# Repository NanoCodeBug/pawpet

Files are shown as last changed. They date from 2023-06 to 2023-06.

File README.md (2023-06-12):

# PawPet

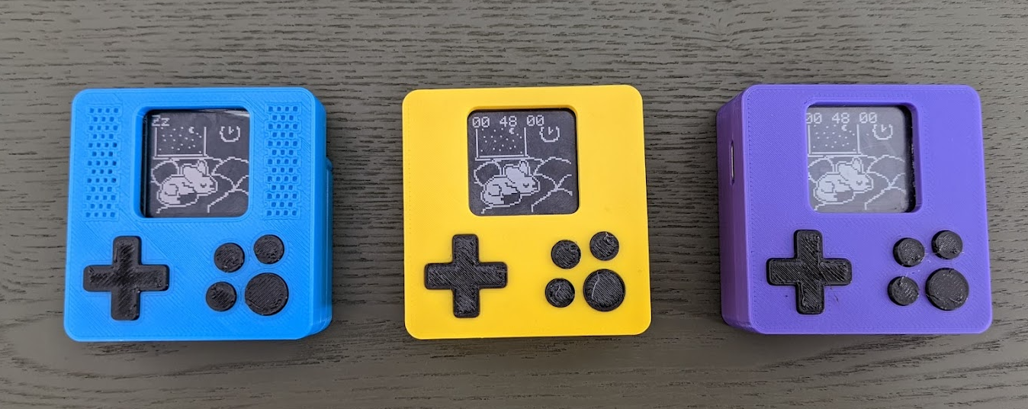
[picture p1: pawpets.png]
PawPet


A virtual pet using the atsamd21g and sharp memory lcd, runs off of 2xAAA for a couple of months. 
See [PawPet on Hacakday.io](https://hackaday.io/project/183032-paw-pet) for full gallery.

This is a rewrite in Rust of the original (and unfinished) arduino based code. That codebase is preserved at [PawPet Arduino](https://github.com/NanoCodeBug/pawpet-arduino).

# Simulator
A webasm simulator of the pawpet using wasm-pack.

This is not a cycle accurate emulator, it hooks the update/render functions to an html5 canvas and maps the core peripherals to web-asm compatible hooks.

1. Install the [Rust](https://www.rust-lang.org/tools/install) SDK

2. Install [wasm-pack](https://rustwasm.github.io/wasm-pack/) (also avaiable via `cargo install wasm-pack`)

3. Run the build script
```
cd pawsim
scripts/build.ps1
```

`index.html` can then be live hosted from the `pawsim\bin` folder, see [pawpet web simulator](https://www.nanocodebug.com/pawpet/index.html) for a working web simulator. 

# Firmware Build Instructions

## Windows
1. Install the [Rust](https://www.rust-lang.org/tools/install) SDK

2. Run sdk-setup, which will setup the rust target dependencies
```
cd pawpet
tools/sdk-setup.ps1
```

3. Run build script
```
cd pawpet
tools/build.ps1
```

## Linux
1. Install [powershell](https://learn.microsoft.com/en-us/powershell/scripting/install/installing-powershell-on-linux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) (i'm sorry, I'll fix this soon)

2. Install the [Rust](https://www.rust-lang.org/tools/install) SDK
3. Install linux dependencies (Ubuntu 20.04) 
```
apt install build-essential libusb-dev libusb-1.0-0-dev libudev-dev pkg-config 
```
4. Run sdk-setup, which will setup the rust target dependencies
```
pwsh
cd pawpet
tools/sdk-setup.ps1
```

5. Run build script
```
pwsh
cd pawpet
tools/build.ps1
```

## Bootloader Flashing
- TODO new hf2 bootloader that supports updating internal flash and extracting save files
- TODO have bootloader support fuse setting

1. disable boot prot fuses
2. flash bootloader generated by `pawboot` module
3. set boot brotection fuses to 16kb (bootprot fuse value 0x2)
4. disable BOD33 fuse 

## Updating Pawpet
- `pawcon` tool supports restarting the pawpet into update mode and flashing new content to its internal storage

# Licensing 

## Code
All code is licensed under the MIT license.

## Assets
All graphics, art, and 3d models are licensed under the Creative Commons Attribution-NonCommercial 4.0 International Public License.

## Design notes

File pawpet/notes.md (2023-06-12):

# TODO
- music playback, music file format
- battery consumption tests

## perf notes
- base screen ~ 5 ms to render empty (battery + peakms counter) frame. 

## Long Term Todo

Bootloader Custom:
- move hf2 file write logic to bootloader, as well as display rendering logic for status
- require hf2 rust impl that can do flash page writes
- would need larger bootloader segment based on file size tests so far, not clear where extra size is comming from compared to c++ bootloader 

## rust firmware validation
- power save tests again
- measure vcom toggle to verify cycling in suspend and wake

# Board Revision Ideas:

revision with p channel mosfets
- that disconnect display power

revision with ldo and p-channel to disconnect battery
- usb power support, see badger2040 switchover design

revision with simple ni-mh charger
- would need big warnings to only use ni-mh batteries

revision with sepearte daughter board for input, more flexibility in case design

revision with silicon contact-pad style buttons, re use existing buttons or cast own

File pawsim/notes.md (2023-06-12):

# todo:
- fm audio synth for beeper
https://rustwasm.github.io/docs/wasm-bindgen/examples/web-audio.html

- frame rate not updating between state changes, need to requery on interval?
- frame rate not syncing, simulator too fast, setInterval drift or issue with main loop?

- onscreen buttons

- look into createImageBitmap?

- remove dependency on wasm-pack
https://rustwasm.github.io/docs/wasm-bindgen/examples/without-a-bundler.html

interesting examples:
https://rustwasm.github.io/docs/wasm-bindgen/examples/2d-canvas.html

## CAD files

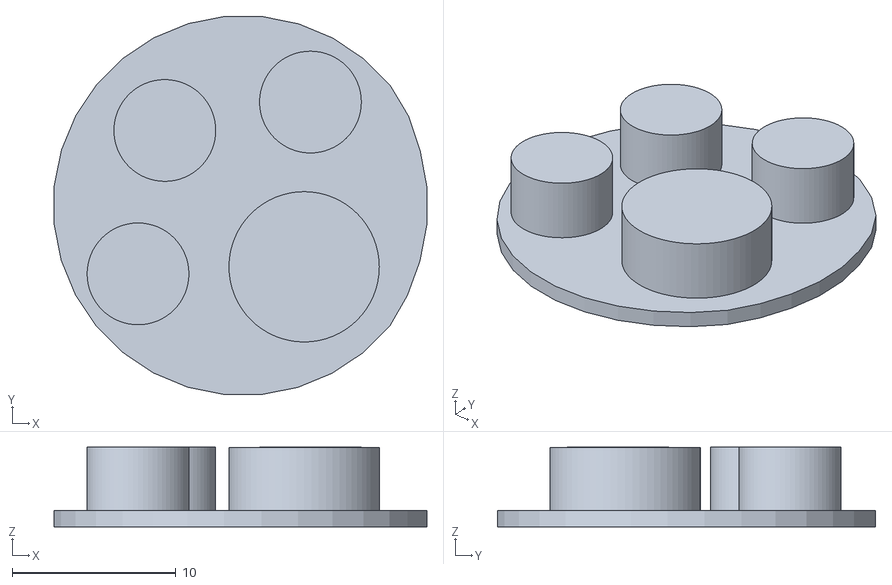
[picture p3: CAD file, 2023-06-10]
case/pawsome-v8-prod-r1-pawPad.stl
22.8 x 23.1 x 4.86

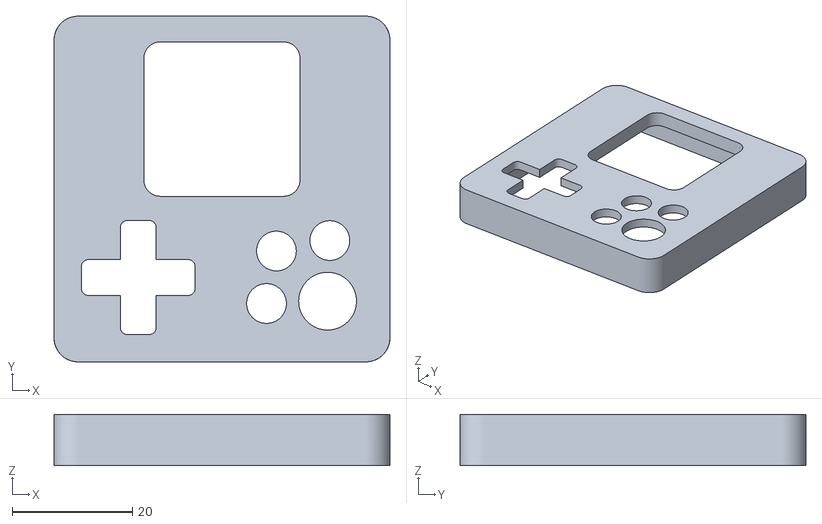
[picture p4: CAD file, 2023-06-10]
case/pawsome-v7-debug-r3-front.stl
55.9 x 57.5 x 8.56

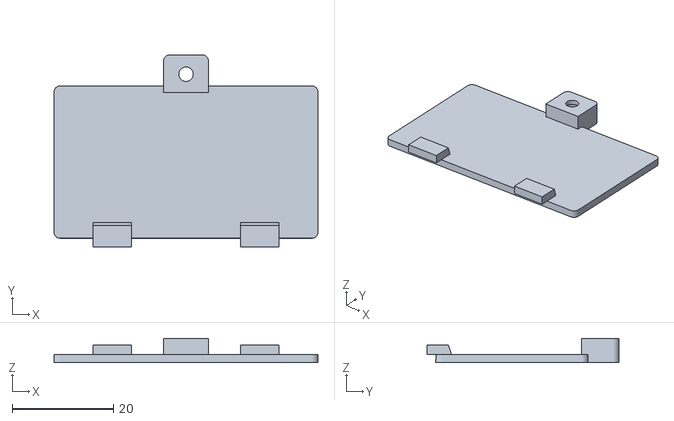
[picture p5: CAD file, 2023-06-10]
case/pawsome-v8-prod-r1-battery-door.stl
52.0 x 37.9 x 4.79

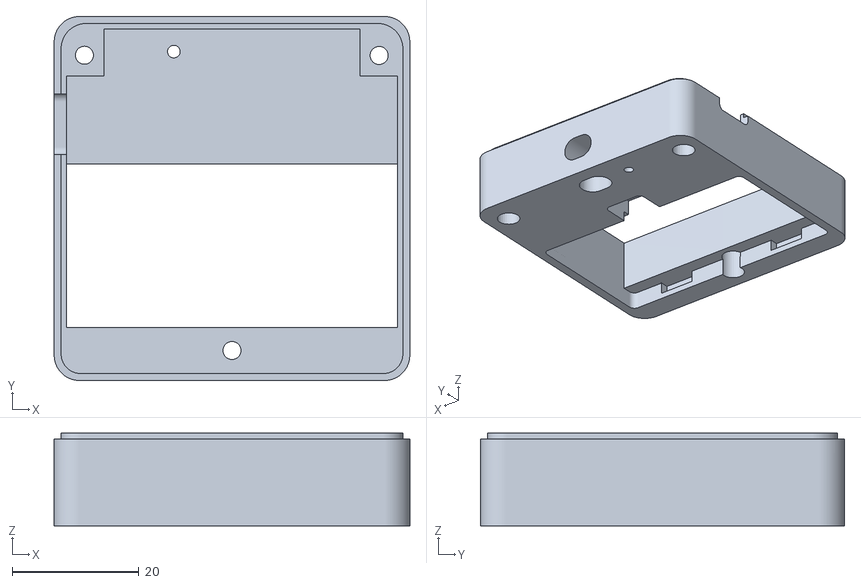
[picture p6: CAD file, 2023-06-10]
case/pawsome-v8-prod-r1-back.stl
56.2 x 57.5 x 14.7

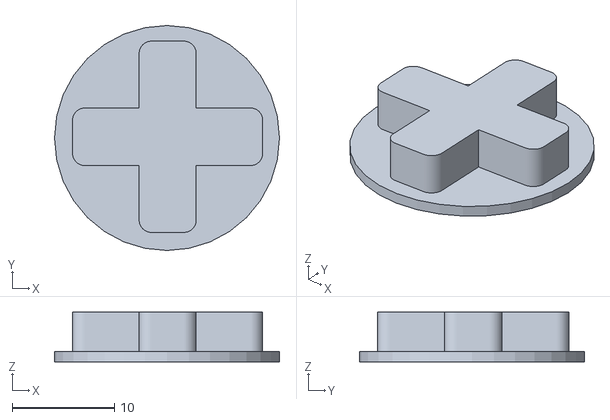
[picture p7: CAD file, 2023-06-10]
case/pawsome-v7-debug-r3-dPad.stl
22.0 x 22.0 x 4.87

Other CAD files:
case/pawsome-v7-debug-r3-pawPad.stl
case/pawsome-v7-debug-r3-back.stl
case/pawsome-v8-prod-r1-dPad.stl
case/pawsome-v7-debug-r3-battery-door.stl
case/pawsome-v8-prod-r1-front.stl

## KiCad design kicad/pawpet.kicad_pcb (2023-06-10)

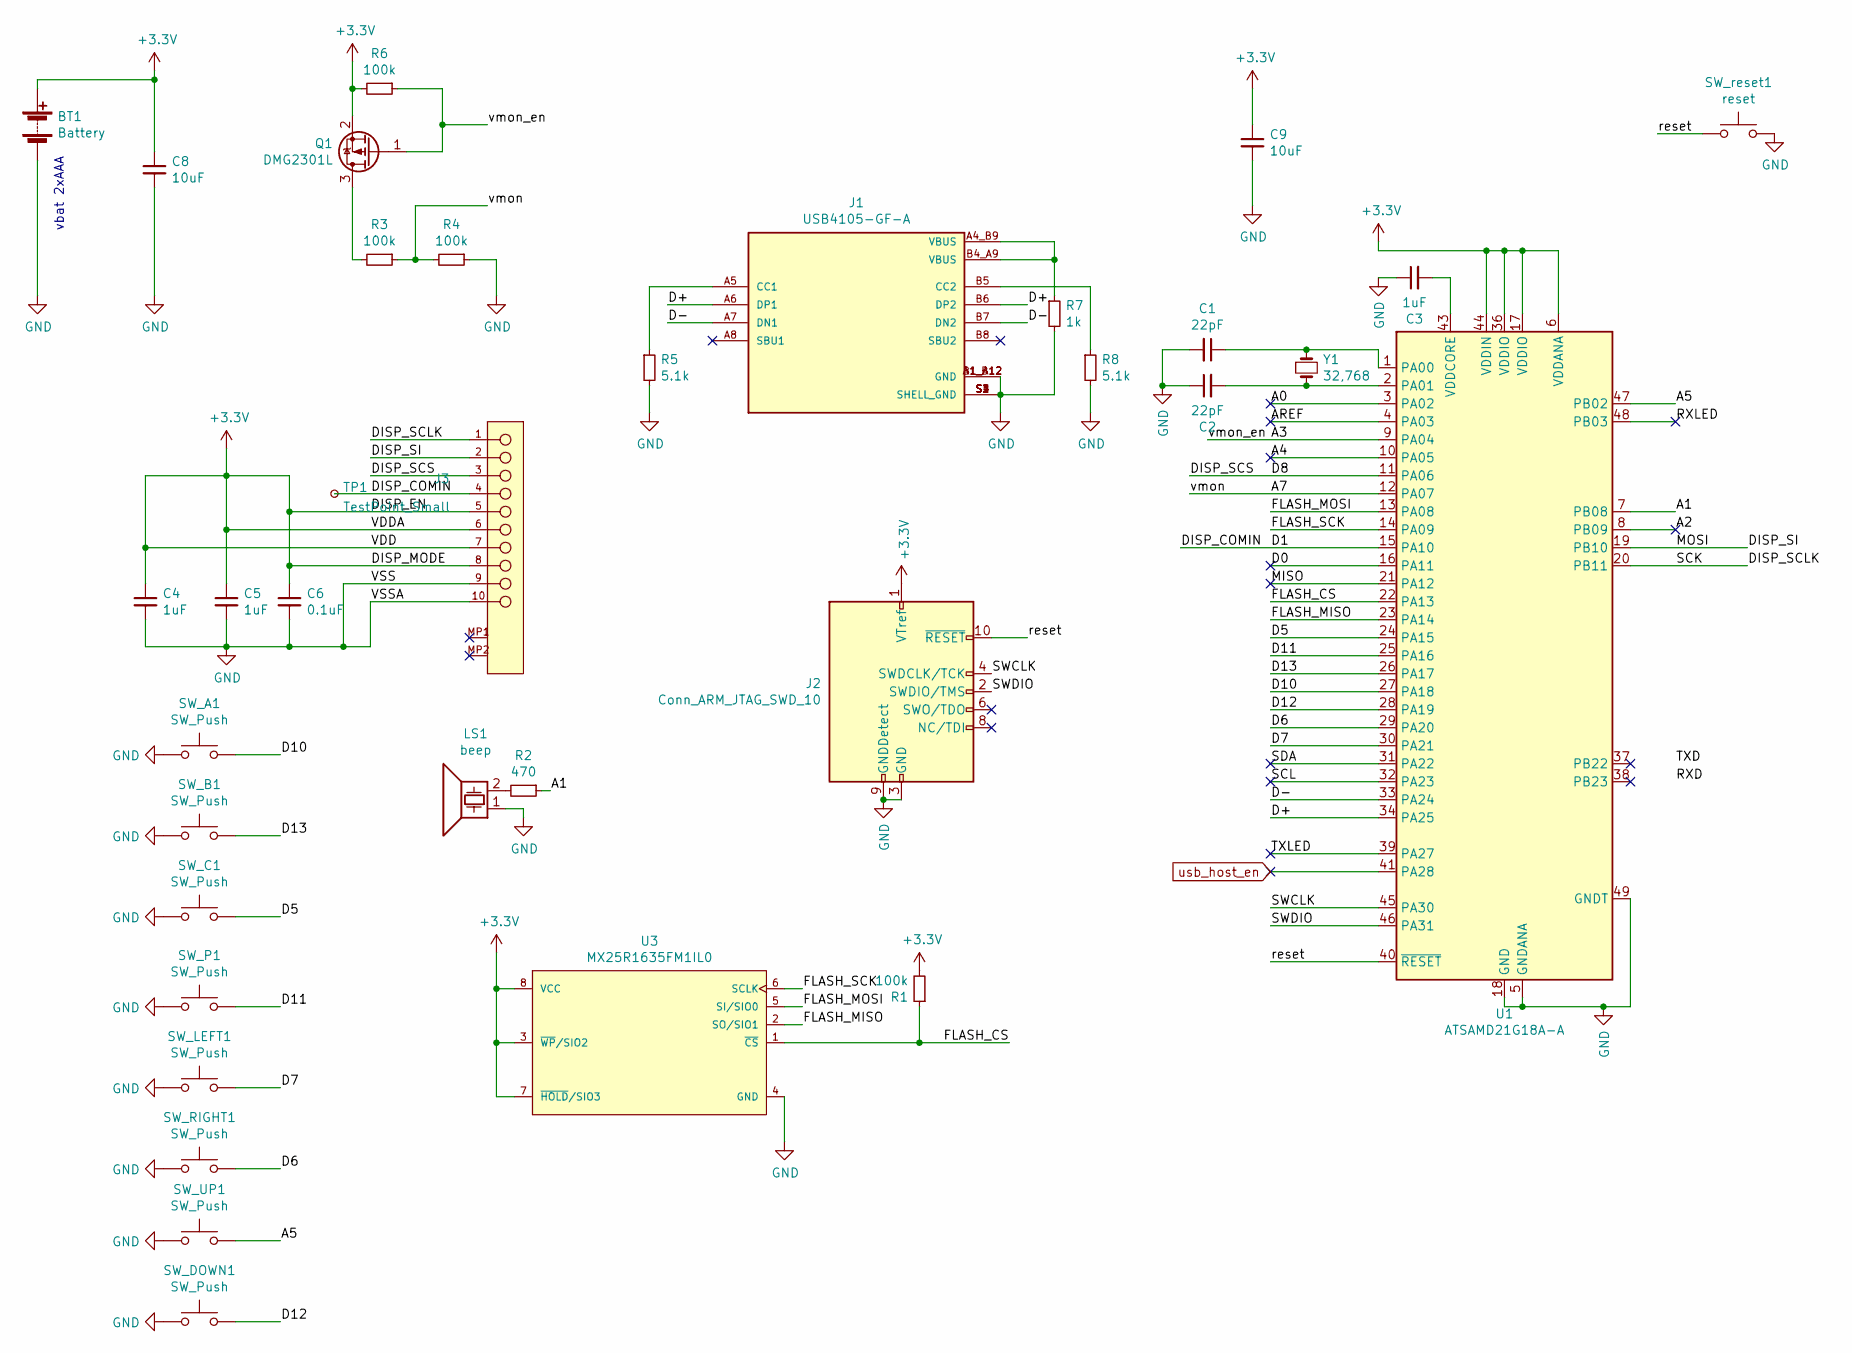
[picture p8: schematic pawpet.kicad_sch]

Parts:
BT1: Battery; BAT_BC2AAAPC
C1, C2: 22pF; C_0805_2012Metric
C3, C4, C5: 1uF; C_0805_2012Metric
C6: 0.1uF; C_0805_2012Metric
C8, C9: 10uF; C_0805_2012Metric
J1: USB4105-GF-A; GCT_USB4105-GF-A; PARTREV A3
J2: Conn_ARM_JTAG_SWD_10; Tag-Connect_TC2030-IDC-NL_2x03_P1.27mm_Vertical
J3: MOLEX; Molex-52892-1033-Manufacturer_Recommended
LS1: beep; Buzzer_Murata_PKMCS0909E4000-R1
Q1: DMG2301L; SOT-23
R1, R3, R4, R6: 100k; R_0805_2012Metric
R2: 470; R_0805_2012Metric
R5, R8: 5.1k; R_0805_2012Metric
R7: 1k; R_0805_2012Metric
SW_A1: SW_Push; SW_SPST_EVQQ2
SW_B1: SW_Push; SW_SPST_EVQQ2
SW_C1: SW_Push; SW_SPST_EVQQ2
SW_DOWN1: SW_Push; SW_SPST_EVQQ2
SW_LEFT1: SW_Push; SW_SPST_EVQQ2
SW_P1: SW_Push; SW_SPST_EVQQ2
SW_RIGHT1: SW_Push; SW_SPST_EVQQ2
SW_UP1: SW_Push; SW_SPST_EVQQ2
SW_reset1: reset; SW_SPST_PTS810_handsolder
TP1: TestPoint_Small; TestPoint_Pad_1.0x1.0mm
U1: ATSAMD21G18A-A; TQFP-48-1EP_7x7mm_P0.5mm_EP5x5mm
U3: MX25R1635FM1IL0; SOIC-8_5.23x5.23mm_P1.27mm
Y1: 32,768; Crystal_SMD_2012-2Pin_2.0x1.2mm

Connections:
+3V3: BT1.1 (+), C4.1, C5.1, C6.1, C8.1, C9.1, J2.1 (VTref), J3.5, J3.6, J3.7, J3.8, Q1.2 (S), R1.2, R6.2, U1.6 (VDDANA), U1.17 (VDDIO), U1.36 (VDDIO), U1.44 (VDDIN), U3.3 (~WP/SIO2), U3.7 (~HOLD/SIO3), U3.8 (VCC)
/A0: U1.3 (PA02)
/A1: R2.1, U1.7 (PB08)
/A2: U1.8 (PB09)
/A3: Q1.1 (G), R6.1, U1.9 (PA04)
/A4: U1.10 (PA05)
/A5: SW_UP1.2, U1.47 (PB02)
/A7: R3.1, R4.2, U1.12 (PA07)
/AREF: U1.4 (PA03)
/D0: U1.16 (PA11)
/D1: J3.4, TP1.1, U1.15 (PA10)
/D5: SW_C1.2, U1.24 (PA15)
/D6: SW_RIGHT1.2, U1.29 (PA20)
/D7: SW_LEFT1.2, U1.30 (PA21)
/D8: J3.3, U1.11 (PA06)
/D10: SW_A1.2, U1.27 (PA18)
/D11: SW_P1.2, U1.25 (PA16)
/D12: SW_DOWN1.2, U1.28 (PA19)
/D13: SW_B1.2, U1.26 (PA17)
/D+: J1.A6 (DP1), J1.B6 (DP2), U1.34 (PA25)
/D-: J1.A7 (DN1), J1.B7 (DN2), U1.33 (PA24)
/DISP_SCLK: J3.1, U1.20 (PB11)
/DISP_SI: J3.2, U1.19 (PB10)
/FLASH_CS: R1.1, U1.22 (PA13), U3.1 (~CS)
/FLASH_MISO: U1.23 (PA14), U3.2 (SO/SIO1)
/FLASH_MOSI: U1.13 (PA08), U3.5 (SI/SIO0)
/FLASH_SCK: U1.14 (PA09), U3.6 (SCLK)
/MISO: U1.21 (PA12)
/RXLED: U1.48 (PB03)
/SCL: U1.32 (PA23)
/SDA: U1.31 (PA22)
/SWCLK: J2.4 (SWDCLK/TCK), U1.45 (PA30)
/SWDIO: J2.2 (SWDIO/TMS), U1.46 (PA31)
/TXLED: U1.39 (PA27)
/reset: J2.10 (~RESET), SW_reset1.1, U1.40 (~RESET)
GND: BT1.2 (-), C1.2, C2.1, C3.1, C4.2, C5.2, C6.2, C8.2, C9.2, J1.A1_B12 (GND), J1.B1_A12 (GND), J1.S1 (SHELL_GND), J1.S2 (SHELL_GND), J1.S3 (SHELL_GND), J1.S4 (SHELL_GND), J2.3 (GND), J2.5 (GND), J2.9 (GNDDetect), J3.9, J3.10, LS1.1, R4.1, R5.2, R7.2, R8.2, SW_A1.1, SW_B1.1, SW_C1.1, SW_DOWN1.1, SW_LEFT1.1, SW_P1.1, SW_RIGHT1.1, SW_UP1.1, SW_reset1.2, U1.5 (GNDANA), U1.18 (GND), U1.35 (GND), U1.42 (GND), U1.49 (GNDT), U3.4 (GND)
unnamed: C1.1, U1.1 (PA00), Y1.1
unnamed: C2.2, U1.2 (PA01), Y1.2
unnamed: C3.2, U1.43 (VDDCORE)
unnamed: J1.A4_B9 (VBUS), J1.B4_A9 (VBUS), R7.1
unnamed: J1.A5 (CC1), R5.1
unnamed: J1.B5 (CC2), R8.1
unnamed: LS1.2, R2.2
unnamed: Q1.3 (D), R3.2
usb_host_en: U1.41 (PA28)

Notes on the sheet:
vbat 2xAAA

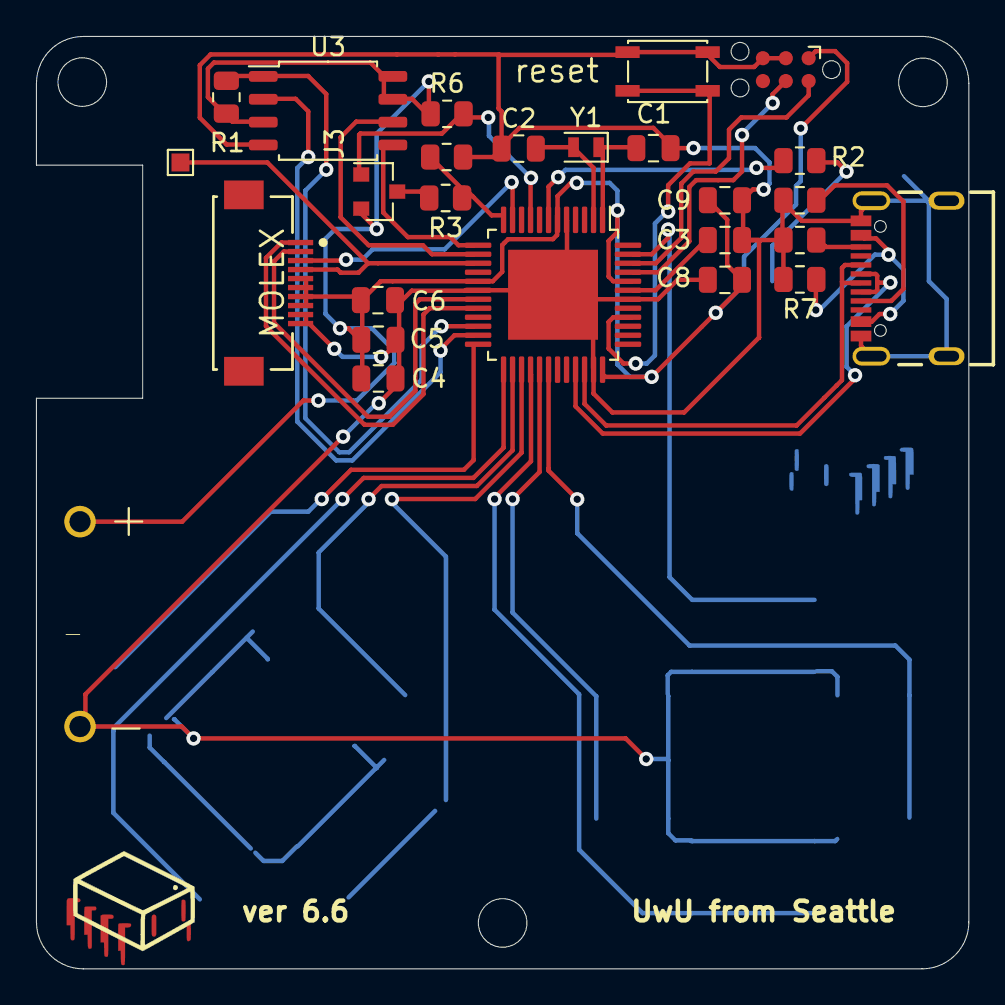
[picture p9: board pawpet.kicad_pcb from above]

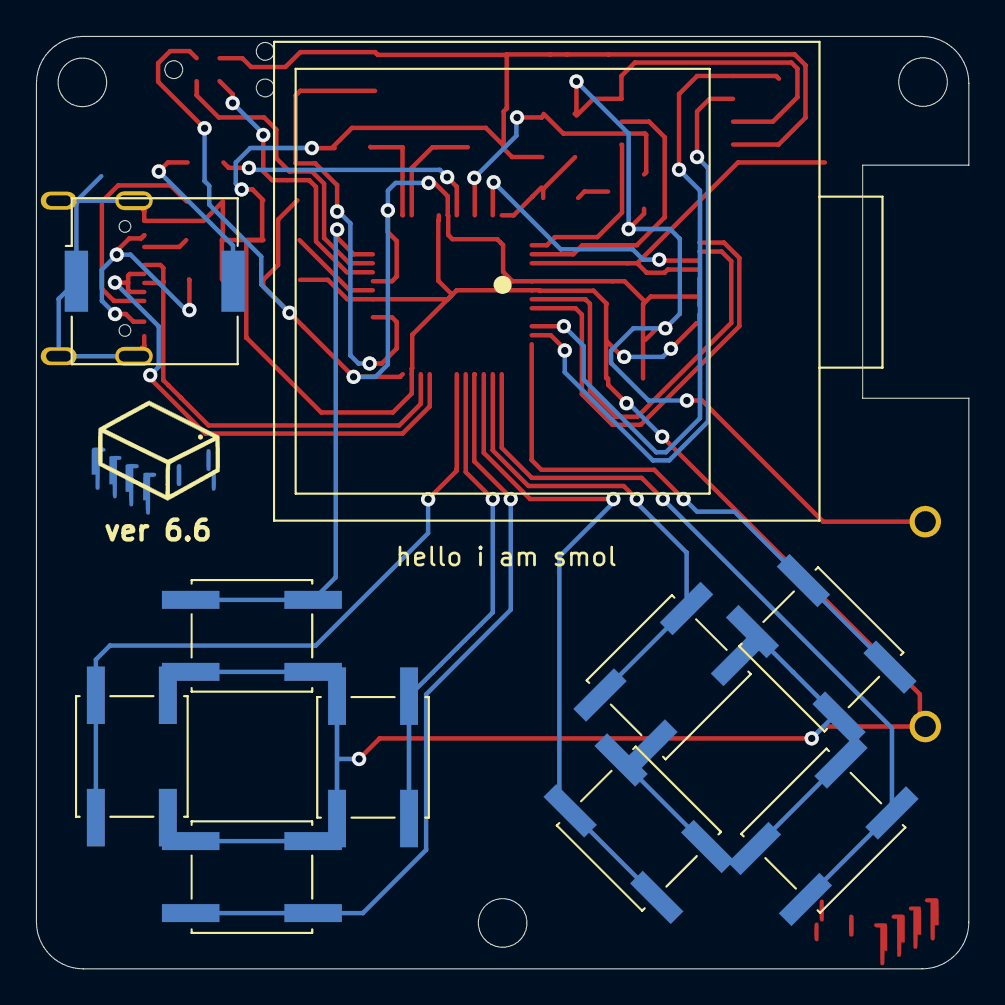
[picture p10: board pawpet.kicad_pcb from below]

Board: 2 copper layers, 51.8 x 51.8 mm, 38 parts (11 on the bottom side), 34 nets.

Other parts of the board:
Ref**: Val**; kicad-drawing
Ref**#2: Val**; kicad-drawing
hello i am smol: Sharp_128x128_LS013B7DH03

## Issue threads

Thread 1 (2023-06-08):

SDL2_DIR evaluates to wrong location

Coolfeather2, 2023-06-08:
While $ENV:SDL2_DIR is set to "$projectRoot\simulator\SDL2"
CMAKE seems to change this to:
SDL2_DIR:PATH=<FULLPATH OF $projectRoot>/simulator/SDL2/cmake

This causes issues with ./simulator/CMakeLists.txt on line 57 as:
```
    configure_file(${SDL2_DIR}/lib/x64/SDL2.dll ${CMAKE_CURRENT_BINARY_DIR} COPYONLY)
```
evalutes to:
```
    configure_file(<FULLPATH OF $projectRoot>/simulator/SDL2/cmake/lib/x64/SDL2.dll ${CMAKE_CURRENT_BINARY_DIR} COPYONLY)
```
as you can see we have an issue here:
`<FULLPATH OF $projectRoot>/simulator/SDL2/cmake/lib/x64/SDL2.dll` does not exist
as SDL2-devel-[version]-VC.zip has the following folder layout:
```
SDL2/
├── cmake/
│   ├── sdl2-config-version.cmake
│   └── sdl2-config.cmake
└── lib/
     └── x64/
          └── SDL2.dll
```

Not sure if this is an issue isolated to my machine with cmake changing SDL2_DIR?

to work around this issue, I have made a copy of the lib folder and placed it into the cmake folder...

I have successfully got the simulator running and have updated the readme which I'll open a PR for.

NanoCodeBug, 2023-06-08:
thanks for your interest in the project!
iirc from the last time I touched this, the sdl libs had to be copied to the output manually, that line was never correct.
glad to know it was cmake changing the variables underneath the environment.

I'm actively working on the pawpet, but under a new codebase and simulator that's Rust based and uses the html5 canvas through webassembly directly, avoiding the SDL dependency entirely. Once the new codebase has parity with this one it will be uploaded to github.

NanoCodeBug, 2023-06-10:
I don't have plans to continue the arduino based implementation at this time, but if you would like to look at the Rust variant, its up at https://github.com/NanoCodeBug/pawpet now.

thanks again!

NanoCodeBug, 2023-06-10:
merged

NanoCodeBug, 2023-06-10:
I don't have plans to continue the arduino based implementation at this time, but if you would like to look at the Rust variant, its up at https://github.com/NanoCodeBug/pawpet now.

thanks again!

Closed 2023-06-10.

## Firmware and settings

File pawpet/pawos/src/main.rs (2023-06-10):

#![no_std]
#![no_main]

pub extern crate cortex_m_rt;
pub use cortex_m_rt::entry;
pub use cortex_m_rt::exception;

use rtt_target::{debug_rprintln, rtt_init_print};

// extern crate alloc;
// use embedded_alloc::Heap;
// use hal::watchdog::WatchdogTimeout;
// use core::panic::PanicInfo;
// use core::alloc::Layout;

// #[global_allocator]
// static HEAP: Heap = Heap::empty();

use hf2hid::HF2Monitor;

use bsp::hal;
use bsp::pac;
// use core::fmt::Write;
use pawbsp as bsp;

use panic_halt as _;

use cortex_m::interrupt::free as disable_interrupts;
use cortex_m::peripheral::NVIC;
use cortex_m::peripheral::SCB;
use usb_device::bus::UsbBusAllocator;
use usb_device::prelude::*;
use usbd_hid::descriptor::generator_prelude::*;
use usbd_hid::hid_class::HIDClass;

use bsp::{periph_alias, pin_alias};
use hal::adc::Adc;
use hal::clock::{ClockGenId, ClockSource, GenericClockController};
use hal::dmac::{DmaController, PriorityLevel};
use hal::eic::{pin::Sense, EIC};
use hal::fugit::RateExtU32;

use hal::prelude::*;
use hal::rtc;
use hal::usb::UsbBus;
use pac::{interrupt, CorePeripherals, Peripherals};

use crate::sleepy_dog::SleepyDog;
use pawdevicetraits::*;

static mut USB_ALLOCATOR: Option<UsbBusAllocator<UsbBus>> = None;
static mut USB_BUS: Option<UsbDevice<UsbBus>> = None;
static mut USB_HID: Option<HIDClass<UsbBus>> = None;
// static mut WDT_SLEEPYDOG: Option<SleepyDog> = None;

use pawdevices::*;
static mut SYS_TIMER: Option<sys_timer::SysTimer> = None;

use hf2hid;

use embedded_graphics::{pixelcolor::BinaryColor, prelude::*};

use spi_memory::series25::Flash;

#[interrupt]
fn WDT() {
    sleepy_dog::SleepyDog::get()
        .unwrap()
        .clear_disable_interrupt();
}

#[gen_hid_descriptor(
     (collection = APPLICATION, usage_page = VENDOR_DEFINED_START, usage = 0x01) = {
        (usage = 0x01,) = {
            #[item_settings data,variable,absolute] in_buf=input;
        };

        (usage = 0x01,) = {
        #[item_settings data,variable,absolute] out_buf=output;
        };

        (usage = 0x01,) = {
        #[item_settings data,variable,absolute] feature_buf=feature;
        };
     }
 )]
struct CustomBidirectionalReport {
    out_buf: [u8; 64],
    in_buf: [u8; 64],
    feature_buf: u8,
}

// const HID_DESCRIPTOR: &'static [u8] = &[
//     0x06, 0x97, 0xFF, // usage page vendor 0x97 (usage 0xff97 0x0001)
//     0x09, 0x01, // usage 1
//     0xA1, 0x01, // collection - application
//     0x15, 0x00, // logical min 0
//     0x26, 0xFF, 0x00, // logical max 255
//     0x75, 8, // report size 8
//     0x95, 64, // report count 64
//     0x09, 0x01, // usage 1
//     0x81, 0x02, // input: data, variable, absolute
//     0x95, 64, // report count 64
//     0x09, 0x01, // usage 1
//     0x91, 0x02, // output: data, variable, absolute
//     0x95, 1, // report count 1
//     0x09, 0x01, // usage 1
//     0xB1, 0x02, // feature: data, variable, absolute
//     0xC0, // end
// ];

fn init() -> (
    rtc::Rtc<rtc::ClockMode>,
    Flash<bsp::FlashSpi, bsp::FlashCs>,
    display::LS013B7DH03,
    buttons::PawButtons,
    tone::Tone,
    battery_monitor::BatteryMonitor,
) {
    rtt_init_print!();
    debug_rprintln!("Hello, world!");

    // {
    //     use core::mem::MaybeUninit;
    //     const HEAP_SIZE: usize = 1024;
    //     static mut HEAP_MEM: [MaybeUninit<u8>; HEAP_SIZE] = [MaybeUninit::uninit(); HEAP_SIZE];
    //     unsafe { HEAP.init(HEAP_MEM.as_ptr() as usize, HEAP_SIZE) }
    // }

    let mut peripherals = Peripherals::take().unwrap();
    let mut core = CorePeripherals::take().unwrap();
    let pins = bsp::Pins::new(peripherals.PORT);

    // setup core objects
    let gclk = peripherals.GCLK;
    let sysctrl = &mut peripherals.SYSCTRL;
    let nvmctrl = &mut peripherals.NVMCTRL;
    let eic = peripherals.EIC;
    let rtc = peripherals.RTC;

    // TODO enable watchdog in early setup process to catch initialization deadlocks?
    sleepy_dog::SleepyDog::new(peripherals.WDT);
    sleepy_dog::SleepyDog::get().unwrap().disable();

    let mut clocks =
        GenericClockController::with_internal_32kosc(gclk, &mut peripherals.PM, sysctrl, nvmctrl);

    // GCLK 3 used for watchdog and EIC, 32k/256 = 125 hz per tick
    let eic_watchdog_clock = clocks
        .configure_gclk_divider_and_source(ClockGenId::GCLK3, 256, ClockSource::OSCULP32K, false)
        .unwrap();

    clocks.configure_standby(ClockGenId::GCLK3, true);

    let eic_clock = clocks.eic(&eic_watchdog_clock).unwrap();
    let mut eic = EIC::init(&mut peripherals.PM, eic_clock, eic);

    let _wdt_clock = clocks.wdt(&eic_watchdog_clock).unwrap();

    // Errata 1.5.8: disable flash sleep or discard first two reads from flash on wake
    nvmctrl.ctrlb.modify(|_, w| w.sleepprm().disabled());

    // RTC Setup
    // get the internal 32k running at 1024 Hz for the RTC
    let timer_clock = clocks
        .configure_gclk_divider_and_source(ClockGenId::GCLK2, 32, ClockSource::XOSC32K, true)
        .unwrap();
    clocks.configure_standby(ClockGenId::GCLK2, true);
    let rtc_clock = clocks.rtc(&timer_clock).unwrap();
    let rtc = rtc::Rtc::clock_mode(rtc, rtc_clock.freq(), &mut peripherals.PM);

    // TODO validate that this bit is not cleared on wakeup
    core.SCB.set_sleepdeep();

    // Setup input pins
    let mut button_p = pins.button_p.into_pull_up_ei();
    button_p.sense(&mut eic, Sense::FALL);
    button_p.enable_interrupt(&mut eic);
    button_p.enable_interrupt_wake(&mut eic);

    let button_a = pins.button_a.into_pull_up_input();
    let button_b = pins.button_b.into_pull_up_input();
    let button_c = pins.button_c.into_pull_up_input();
    let button_up = pins.button_up.into_pull_up_input();
    let button_right = pins.button_right.into_pull_up_input();
    let button_down = pins.button_down.into_pull_up_input();
    let button_left = pins.button_left.into_pull_up_input();

    let buttons = buttons::PawButtons::new(
        button_a,
        button_b,
        button_c,
        button_p,
        button_up,
        button_right,
        button_down,
        button_left,
    );

    // power monitor
    let mut vmon_enable: bsp::EnableVBAT = pins.vmon_enable.into_push_pull_output();
    vmon_enable.set_high().unwrap();

    let vmon_read: bsp::InputVBAT = pin_alias!(pins.vmon_read).into();

    let adc = Adc::adc(peripherals.ADC, &mut peripherals.PM, &mut clocks);

    let bat_mon = battery_monitor::BatteryMonitor::new(adc, vmon_enable, vmon_read);

    // setup sercom2 for flash
    let flash_sercom = periph_alias!(peripherals.flash_sercom);
    let flash_spi = bsp::flash_spi(
        &mut clocks,
        8.MHz(),
        flash_sercom,
        &mut peripherals.PM,
        pins.flash_sclk,
        pins.flash_mosi,
        pins.flash_miso,
    );

    let flash_cs: bsp::FlashCs = pin_alias!(pins.flash_cs).into();

    let flash = Flash::init(flash_spi, flash_cs).unwrap();

    // setup sercom4 for display
    let spi_sercom = periph_alias!(peripherals.sharp_sercom);
    let sharp_spi = bsp::sharp_spi(
        &mut clocks,
        2.MHz(),
        spi_sercom,
        &mut peripherals.PM,
        pins.sharp_sclk,
        pins.sharp_mosi,
        pins.sharp_miso,
    );

    let disp_cs = pins.disp_cs.into_push_pull_output();

    // DMA setup
    let dmac = peripherals.DMAC;

    // Initialize DMA Controller
    let mut dmac = DmaController::init(dmac, &mut peripherals.PM);

    // Get individual handles to DMA channels
    let channels = dmac.split();
    let chan0 = channels.0.init(PriorityLevel::LVL0);

    // setup clock to 125 hz, using divsel feature
    let vcom_gclock = clocks
        .configure_gclk_divider_and_source(ClockGenId::GCLK4, 256, ClockSource::OSCULP32K, true)
        .unwrap();

    clocks.configure_standby(ClockGenId::GCLK4, true);

    let _vcom_clock = clocks.tcc0_tcc1(&vcom_gclock).unwrap();
    let vcom_pin: bsp::DispComInE = bsp::pin_alias!(pins.disp_comin).into();

    let _vcom_toggler =
        vcom_toggle::VCOMToggle::new(vcom_pin, peripherals.TCC1, &mut peripherals.PM);

    let gclk0 = clocks.gclk0();
    let tc_clock = &clocks.tc4_tc5(&gclk0).unwrap();
    let tone_beeper: bsp::BeeperE = bsp::pin_alias!(pins.beeper_e).into();

    let tone = tone::Tone::new(tone_beeper, peripherals.TC4, tc_clock, &mut peripherals.PM);
    tone.tone(0);

    unsafe {
        core.NVIC.set_priority(interrupt::WDT, 0);
        NVIC::unmask(interrupt::WDT);

        core.NVIC.set_priority(interrupt::USB, 1);
        NVIC::unmask(interrupt::USB);

        core.NVIC.set_priority(interrupt::EIC, 2);
        NVIC::unmask(interrupt::EIC);

        core.NVIC.set_priority(interrupt::DMAC, 3);
        NVIC::unmask(interrupt::DMAC);

        // core.NVIC.set_priority(interrupt::, 4);
        // NVIC::unmask(interrupt::SYSCTRL);
    }

    let mut display = display::LS013B7DH03::new(sharp_spi, chan0, disp_cs);
    display.clear(BinaryColor::Off).ok();
    display.update();
    display.set_rotation(1);

    // initialize USB
    let bus_allocator = unsafe {
        USB_ALLOCATOR = Some(bsp::usb_allocator(
            peripherals.USB,
            &mut clocks,
            &mut peripherals.PM,
            pins.usb_dm,
            pins.usb_dp,
        ));
        USB_ALLOCATOR.as_ref().unwrap()
    };

    unsafe {
        USB_HID = Some(HIDClass::new(
            bus_allocator,
            CustomBidirectionalReport::desc(),
            10,
        ));
        // bootloader is 239a 0015
        USB_BUS = Some(
            UsbDeviceBuilder::new(bus_allocator, UsbVidPid(0x239a, 0xAA00))
                .manufacturer("Nano Heavy Industries")
                .product("Paw Pet")
                .serial_number("PAWPET001")
                .build(),
        );
    }

    let timer = sys_timer::SysTimer::new(core.SYST, &mut clocks);
    unsafe {
        SYS_TIMER = Some(timer);
    };
    // TODO disable unused peripherals according to what is enabled by default
    // TODO conditionally disable peripherals on sleep? both sercoms could probably be turned off between wakeups, dma, etc.

    // TODO setup fat file system access

    return (rtc, flash, display, buttons, tone, bat_mon);
}

// static STORAGE_DATA: &'static [u8] = include_bytes!("../../games/sprites/pet_sit.paw");

#[entry]
fn main() -> ! {
    let (_rtc, mut flash, mut display, mut buttons, tone, mut battery) = init();

    let timer = unsafe { SYS_TIMER.as_mut().unwrap() };

    let id = flash.read_jedec_id().unwrap();
    let rot = flash.read_status().unwrap();
    debug_rprintln!("JDEC {:?} {:?}", id, rot);

    let mut storage = pawdevices::storage_simple::SimpleFlashStorage::new(flash);
    // storage.write_image(STORAGE_DATA, b"petsit");

    // storage.format_storage();

    tone.tone(500);
    timer.delay_ms(250);
    tone.no_tone();
    timer.delay_ms(250);
    tone.tone(700);
    timer.delay_ms(250);
    tone.no_tone();

    let mut hid_mon: HF2Monitor = HF2Monitor::new();

    sleepy_dog::SleepyDog::get()
        .unwrap()
        .start_timeout(sleepy_dog::SleepyDogTimeout::Seconds2);

    let mut paw_runner = games::PawRunner::new();
    let watchdog: &mut SleepyDog = &mut sleepy_dog::SleepyDog::get().unwrap();

    loop {
        // TODO technically systimer start should be up here to maintain proper framerate

        // HF2 monitor loop
        // TODO move to a custom gamestate specific to the firmware version?
        // TODO move entirely to the bootloader
        // OR keep min-small implementation that responds to reboot to bootloader request only
        {
            // todo, move to usb firmware updating state to avoid allocating monitor objects on stack,

            let hid_action = hid_mon.try_recv_packet(poll_packet);

            let command = hid_action.0;
            let packet_type = hid_action.1;

            if command.is_some() {
                watchdog.disable();

                let command = command.unwrap();
                debug_rprintln!("usb: {:X?}", command as u32);

                let mut report_buff: [u8; 4096] = [0; 4096];
                let mut report_len: usize = 0;

                if matches!(packet_type, hf2hid::PacketType::MultiPacket) {
                    // hid packet is multipacket, query until all data found
                    let mut packet_complete = false;
                    while !packet_complete {
                        // debug_rprintln!("multi len: {}", report_len as u32);

                        packet_complete = hid_mon.recv_multi_data_packet(
                            poll_packet,
                            &mut report_buff,
                            &mut report_len,
                        );
                    }

                    // handl multipacket command, could be moved down to next match case at cost of stack size on small packet receive
                    // match command {
                    //     hf2hid::HF2Commands::WriteKeyValue => {}
                    //     _ => {}
                    // }
                }

                match command {
                    hf2hid::HF2Commands::ResetIntoBootloader => {
                        reset_to_boot();
                    }
                    hf2hid::HF2Commands::BinInfo => {
                        hid_mon.send_bin_info_packet(send_packet);
                    }
                    hf2hid::HF2Commands::Info => {
                        hid_mon.send_version_info_packet(send_packet);
                    }
                    // hf2hid::HF2Commands::DMesg => {}
                    // hf2hid::HF2Commands::ListKeys => {}
                    hf2hid::HF2Commands::FormatFileSys => {
                        debug_rprintln!("ERASE START");
                        hid_mon.send_empty_success_packet(send_packet);
                        storage.format_storage();
                        debug_rprintln!("ERASE DONE");
                    }
                    hf2hid::HF2Commands::WriteFile => {
                        // TODO: support single packet files for write-file
                        // aka files that are less than 54 bytes - probably never going to happen
                        // would be super wasteful of the disk min block size of 256

                        if matches!(packet_type, hf2hid::PacketType::SinglePacket) {
                            hid_mon.send_empty_error_packet(send_packet);
                        } else {
                            let key = core::str::from_utf8(&report_buff[0..16])
                                .unwrap()
                                .trim_end_matches(char::from(0));

                            debug_rprintln!("write image '{}' len {}", key, report_len as u32);

                            let res = storage.write_image(&report_buff[16..report_len], &key);
                            if res.is_ok() {
                                hid_mon.send_empty_success_packet(send_packet);
                            } else {
                                hid_mon.send_empty_error_packet(send_packet);
                            }
                        }
                    }
                    _ => {
                        hid_mon.send_empty_not_recognized_packet(send_packet);
                    }
                }
                watchdog.start_timeout(sleepy_dog::SleepyDogTimeout::Seconds2);
            }
        }

        // TODO provide logging function to the gamestate, set by wrapper
        paw_runner.tick(
            &mut display,
            &mut buttons,
            watchdog,
            &tone,
            timer,
            &mut battery,
            &mut storage,
        );

        let sleep_request = paw_runner.sleep_request();
        if sleep_request.is_some() {
            timer.disable();
            sleep(&mut buttons, sleep_request.unwrap());
            timer.enable();
        }
    }
}

pub fn sleep(buttons: &mut buttons::PawButtons, period: WatchdogTimeouts) {
    buttons.enable_interrupt();
    NVIC::mask(interrupt::USB);
    NVIC::unpend(interrupt::USB);
    // NVIC::mask(-1);
    // NVIC::unpend(-1);

    sleepy_dog::SleepyDog::get().unwrap().sleep(period);

    // ensure wakeup is handled without interrupts from other sources
    disable_interrupts(|_| {
        sleepy_dog::SleepyDog::get().unwrap().disable();
        sleepy_dog::SleepyDog::get()
            .unwrap()
            .start_timeout(sleepy_dog::SleepyDogTimeout::Seconds2);

        buttons.disable_interrupt();
        unsafe {
            NVIC::unmask(interrupt::USB);
            // NVIC::unmask(interrupt::SYSCTRL);
        }
    });
}

pub fn reset_to_boot() {
    disable_interrupts(|_| {
        NVIC::mask(interrupt::USB);
        NVIC::unpend(interrupt::USB);
        sleepy_dog::SleepyDog::get().unwrap().disable();

        const DBL_TAP_MAGIC: u32 = 0xf01669ef;
        // base address + ram size - 4 bytes
        const DBL_TAP_PTR: *mut u32 = (0x20000000 + 0x00008000 - 4) as *mut u32;
        unsafe {
            core::ptr::write_volatile(DBL_TAP_PTR, DBL_TAP_MAGIC);
        }
        SCB::sys_reset();
    });
}

fn send_packet(report: &[u8]) {
    disable_interrupts(|_| unsafe {
        USB_HID.as_mut().map(|hid| hid.push_raw_input(&report));
    })
}

fn poll_packet(report: &mut [u8; 64]) -> usize {
    let mut packet_size = 0;
    disable_interrupts(|_| unsafe {
        USB_HID.as_mut().map(|hid| {
            match hid.pull_raw_output(report) {
                Ok(size) => {
                    // hprintln!("{:02X?}", report).unwrap();
                    packet_size = size;
                }
                Err(UsbError::WouldBlock) => {
                    // no pending data
                }
                Err(err) => panic!("Error receiving data {:?}", err),
            }
        });
    });
    packet_size
}

/**
 * TODO: maybe this interrupt isn't frequent enough to catch the poll rate needed?
 * move to a usb-update state that poll this in the update loop between screen refreshes?
 */
#[interrupt]
fn USB() {
    unsafe {
        disable_interrupts(|_| {
            if let Some(usb_dev) = USB_BUS.as_mut() {
                if let Some(hid) = USB_HID.as_mut() {
                    usb_dev.poll(&mut [hid]);

                    // Make the other side happy
                    // let mut buf = [0u8; 16];
                    // let _ = serial.read(&mut buf);
                };
            };
        })
    };
}

#[interrupt]
fn EIC() {
    // Accessing registers from interrupts context is safe
    let eic = unsafe { &*pac::EIC::ptr() };

    // TODO, is critical section needed here? no data is being modified, should be fine for usb interrupts
    disable_interrupts(|_| {
        // check INTFLAG to validate interrupt source if more than one is in use
        if eic.intflag.read().extint0().bit_is_set() {
            // The interrupt request remains active until the interrupt flag is cleared,
            // the interrupt is disabled or the peripheral is reset. An interrupt flag is
            // cleared by writing a one to the corresponding bit in the INTFLAG register.
            // read more: SAM-D21DA1-Family-Data-Sheet-DS40001882G.pdf # 16.6.5 Interrupts
            eic.intflag.modify(|_, w| w.extint0().set_bit());
        }
    });
}

#[exception]
fn SysTick() {
    let timer = unsafe { SYS_TIMER.as_mut().unwrap() };
    timer.tick();
}

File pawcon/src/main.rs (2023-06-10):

use hf2;
use hidapi::{DeviceInfo, HidApi};
use std::fs;
use std::io;
use std::io::Read;

fn main() {
    // Statements here are executed when the compiled binary is called.

    // Print text to the console.
    println!("Hello World!");

    let api = HidApi::new().expect("Couldn't find system usb");
    let mut device = None;

    'scanner: loop {
        let devices = api.device_list();

        for d in devices {
            let d = d;

            // println!("{}", d.product_string().unwrap_or_default());
            if d.serial_number().unwrap().starts_with("PAWPET")
                || d.product_string().unwrap().starts_with("PawPet")
            {
                device = Some(d);
                break 'scanner;
            }
            // if d.
            // .open_device(&api).unwrap();
        }

        if device.is_none() {
            println!("no device found, retry?");
            let mut buffer = String::new();
            io::stdin().read_line(&mut buffer);
        }
    }

    if device.is_some() {
        let device = device.unwrap();
        println!("{:?}", device);
        println!("{}", device.product_string().unwrap_or_default());
        println!("{}", device.manufacturer_string().unwrap_or_default());
        println!("{}", device.serial_number().unwrap_or_default());

        let device = device.open_device(&api).unwrap();
        // let chk = hf2::checksum_pages(&device, 0x4000, 1);
        let chk = hf2::bin_info(&device);
        println!("{:?}", chk);

        let chk = hf2::info(&device);
        println!("{:?}", chk);

        // let chk = hf2::dmesg(&device);
        // println!("{:?}", chk);

        // let chk = hf2::reset_into_app(&device);
        // println!("{:?}", chk);

        // let chk = hf2::reset_into_bootloader(&device);
        // println!("{:?}", chk);

        let chk = hf2::format_filesystem(&device);
        println!("{:?}", chk);

        let paths = fs::read_dir("../sprites").unwrap();
        let mut found_files = Vec::new();
        let mut total_bytes = 0;
        for path in paths {
            let name = path.as_ref().unwrap().file_name();

            if name.to_str().unwrap_or_default().ends_with(".paw") {
                let path = path.unwrap().path();
                let f = fs::File::open(path.clone()).unwrap();
                let size = f.metadata().unwrap().len();
                total_bytes += size;
                found_files.push(path);
                println!("{:<16} {:4}", name.to_str().unwrap(), size);
            }
        }
        println!("=========================");
        println!("files: {:<3} bytes: {:<6}", found_files.len(), total_bytes);
        println!("=========================");

        for file in found_files {
            let mut f = fs::File::open(file.clone()).unwrap();
            let mut buffer: Vec<u8> = Vec::new();
            f.read_to_end(&mut buffer).expect("failed to read file");
            
            let name = String::from(file.file_name().unwrap().to_str().unwrap());
            let mut split = name.split(".");
            let mut name = String::from(split.next().unwrap());
            name.truncate(16);

            let chk = hf2::send_file(&device, name.as_str(), buffer.clone());
            println!("{:<16} {:?}", name.as_str(), chk);
        }
    }
}
